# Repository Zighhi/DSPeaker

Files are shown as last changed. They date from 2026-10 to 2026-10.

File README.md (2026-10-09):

# DSPeaker

A DIY 2-way active desktop monitor: custom cabinets, an RP2040 running a hand-written fixed-point DSP crossover, and independent DACs giving each speaker its own full crossover network. Every DSP decision here was validated against real acoustic measurement, not tuned by ear.

<p align="center">
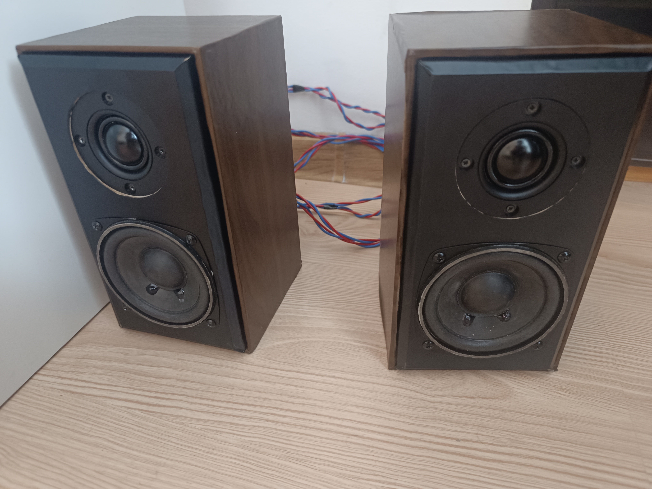
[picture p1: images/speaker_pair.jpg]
The finished stereo pair
  
</p>

## Measured Result

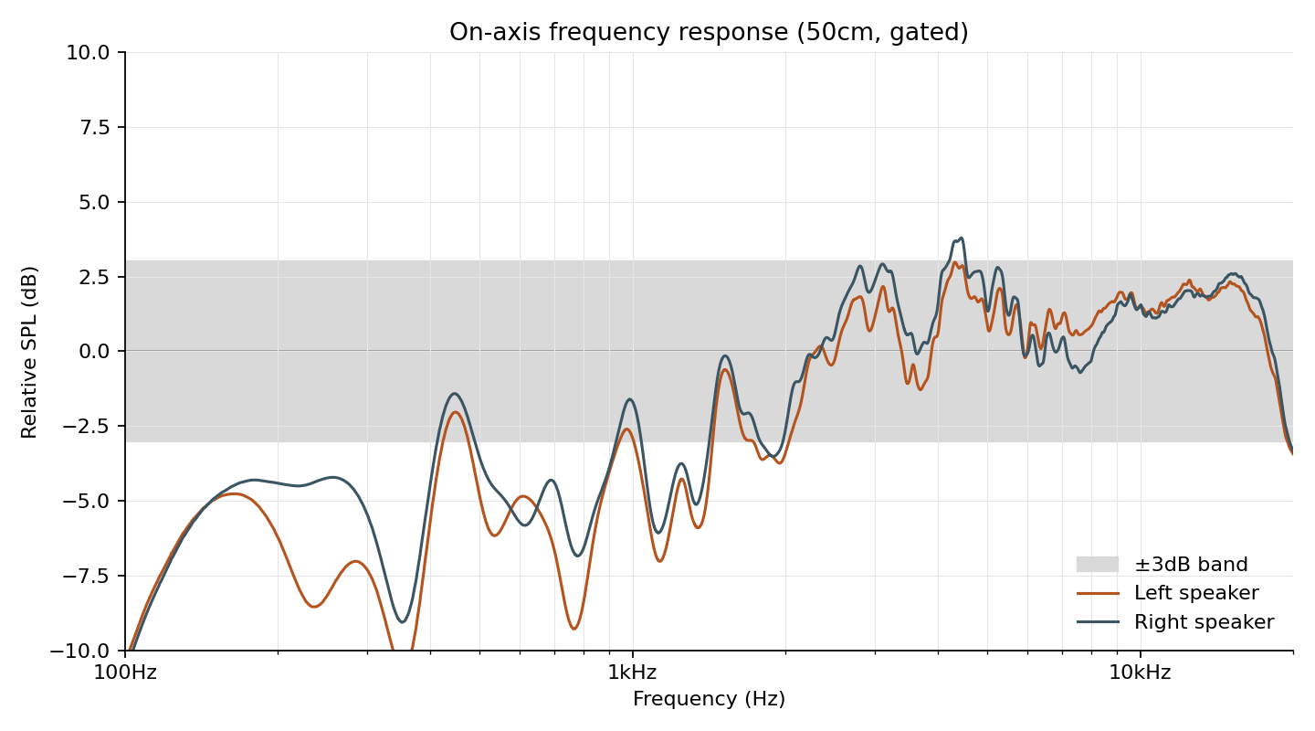
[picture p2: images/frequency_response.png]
On-axis frequency response


Gated 50cm on-axis, both speakers, raw/unsmoothed standard deviation **±2.65dB (Left) / ±2.47dB (Right)** across 100Hz–20kHz.

---

## Hardware

| | |
|---|---|
| **Tweeter** | Dayton Audio ND25FA-4 — 25mm silk dome, 4Ω, Re 3.2Ω, Fs 1350Hz, Qts 1.56, Sd 7.5cm², 90dB @ 2.83V/1m, 20W RMS, manufacturer usable range 2.5–20kHz (full manufacturer datasheet not redistributed here — search "Dayton Audio ND25FA-4" on their site for the original PDF) |
| **Woofer** | Unmarked ~75mm cone driver, Thiele-Small parameters measured directly — see [`driver_measurements`](driver_measurements): Re 5.50–5.57Ω, Fs 128.6–132.5Hz, Qts 1.702–1.858, Vas 0.92L, Sd 44.2cm², ≈81dB @ 1W/1m |
| **Amplification** | TPA3118D2 Class-D, 4 channels total (one per driver — tweeter and woofer never share a channel), run at 12V against a 24V/≈60W rating |
| **DSP** | Raspberry Pi RP2040 (Waveshare RP2040-Zero), no hardware FPU, 48kHz, fixed-point (Q28/Q31) |
| **Converters** | WM8782 ADC (stereo input), 2× PCM5102A DAC — one per speaker, each independently addressed, not a stereo pair sharing one chip |
| **Cabinet** | CNC-cut baffle/frame, front baffle 110×210mm, internal acoustic stuffing |

No standalone schematic exists for the electronics — the actual signal chain is fully specified in the pin-level comments at the top of [`miXZer.c`](firmware/miXZer/miXZer.c), and the real build is visible in the photos below. The perfboard carries the WM8782 ADC input stage, the RP2040-Zero, and the two PCM5102A DAC modules feeding the four TPA3118 amp channels.

<p align="center">
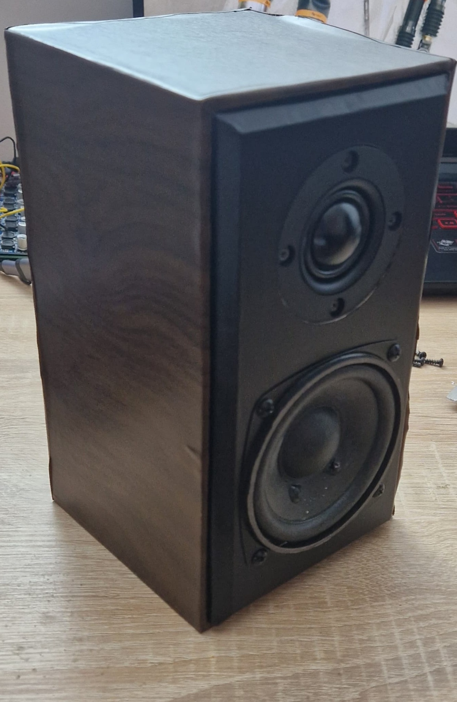
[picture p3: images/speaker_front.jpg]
Tweeter and woofer, front view
  
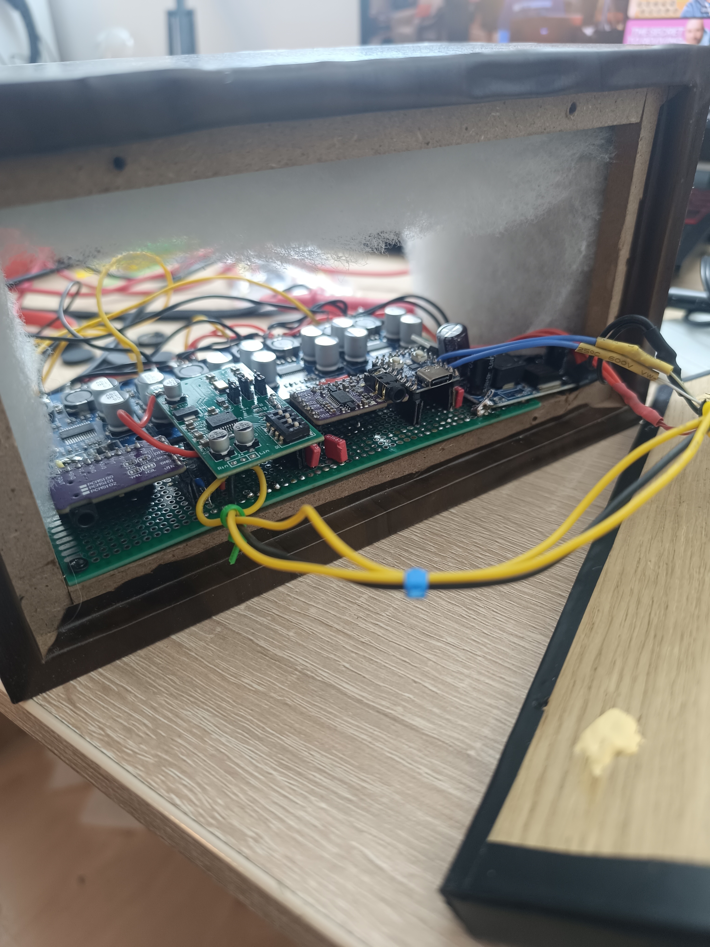
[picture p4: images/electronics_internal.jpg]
The electronics assembly inside the active cabinet
  
</p>

---

## Firmware & DSP

All of it lives in [`miXZer.c`](firmware/miXZer/miXZer.c) — one file, no RTOS, an interrupt-driven double-buffered DMA pipeline running the whole signal chain sample-by-sample in real time.

**Signal path:**
```
ADC (WM8782, stereo in)
      │
      ▼
 Baffle-step shelf (source L/R, pre-split)
      │
      ├──► Tweeter HPF (LR4, 3kHz) ──► amp1 (L) / amp3 (R)
      │
      └──► Woofer LPF (LR4, 3kHz) ──► level pad ──► amp2 (L) / amp4 (R)
```

Left and Right stay fully independent the entire way through — two DACs, two crossovers, never mixed.

**Fixed-point throughout.** The RP2040 has no hardware FPU — a float multiply costs ~80 cycles in software, not viable inside a 48kHz real-time budget. Filters run in Q0.31 where coefficients stay under 1.0, Q3.28 where they don't (the crossover biquads exceed ±1.0), multiplies widened to 64-bit before rescaling to avoid overflow.

**The crossover went through three real iterations:**
1. Two cascaded 1st-order HPF/LPF stages (LR2-equivalent) — a real destructive-interference notch showed up at 1.5–2.2kHz. A delay line made it worse in both directions. Root cause: LR2 only sums flat with one driver's polarity inverted.
2. With that fixed, the tweeter's own mechanical resonance (Fs=1350Hz, Qts 1.56) was only getting ~16dB of attenuation from the 2-pole HPF — audible as a +8–10dB peak at 1.4kHz. Bumping the tweeter HPF to 3 stages fixed the resonance but broke the matched-order flat-sum property, reopening a different ~9–10dB dip.
3. **Final: a real 4th-order Linkwitz-Riley (LR4)** — two cascaded 2nd-order Butterworth biquads per side, matched order, normal (non-inverted) polarity. Steeper than the 3-pole hack (−28.4dB at the tweeter's resonance, vs −24.1dB) *and* matched-order, so it sums flat on its own — verified flat to <1e-13dB across 500Hz–6kHz in the design math. The coefficient design tool is at [`design_tools/test_lr4_crossover.py`](firmware/miXZer/design_tools/test_lr4_crossover.py).

**Baffle-step compensation**: the 110mm baffle width gives a shelf corner at `115/0.11m ≈ 1045Hz`. A +4dB low shelf below that, applied pre-crossover-split, compensates for the cabinet losing half-space loading at low frequencies.

**Level matching**: no tweeter pad survived — estimated values gave wildly inconsistent results session to session, traced to measurement setup rather than the electronics. With no pad at all, a clean measurement showed the woofer running 4.36dB hot; the woofer gets that attenuation instead.

**Live diagnostics over USB serial**, no reflashing between measurement takes: `b`/`t`/`w` for both/tweeter-only/woofer-only, `s` to toggle the baffle-step shelf. A separate firmware, [`channel_id.c`](firmware/miXZer/channel_id.c), confirmed the amp-to-driver mapping by playing a distinct tone per channel: **amp1 = Left tweeter, amp2 = Left woofer, amp3 = Right tweeter, amp4 = Right woofer.**

---

## The Stereo-Imaging Bug

The single most important fix in the project, and it was silent — nothing sounded obviously broken. The original design treated the I2S Left/Right *slot* as meaning tweeter/woofer, and fed the second DAC as a literal mirror of the first. Source-Left reached *both* tweeters, source-Right reached *both* woofers — true stereo imaging was scrambled the whole time. Fixed by splitting each speaker's own source channel into its own tweeter/woofer feed, with the second DAC's buffer filled independently every sample instead of mirrored.

---

## Repository Structure

```
firmware/
├── miXZer/        Current firmware — miXZer.c (main DSP), channel_id.c
│                   (driver-identification tool), lib/ (PIO I2S driver),
│                   design_tools/ (LR4 coefficient calculator)
└── build_tools/    auto_flash_rp2040.py — the UF2 flashing script actually used

02_CAD_3D/
├── Cabinet_STEP_Models/   STEP models of the cabinets, baffles and frames
└── layout/                Perfboard layout (DIY Layout Creator) + PDF and netlist

driver_measurements/   Measured Thiele-Small parameters for both woofers

images/                 Build photos and the measured frequency response chart
```

---

## Building It Yourself

**Toolchain** (not vendored here — install yourself, pinned to what this was built/tested with):
- `arm-none-eabi-gcc` 14.2.1 (Release)
- CMake 3.29+
- Ninja
- [Raspberry Pi Pico SDK](https://github.com/raspberrypi/pico-sdk) 2.2.0

**Build:**
```
cd firmware/miXZer
python build_mixzer.py
```

**Flash** (board in BOOTSEL mode):
```
cd firmware/build_tools
python auto_flash_rp2040.py
```

By default this flashes `miXZer.uf2`; pass an explicit path as the first argument to flash something else (e.g. `channel_id.uf2`).

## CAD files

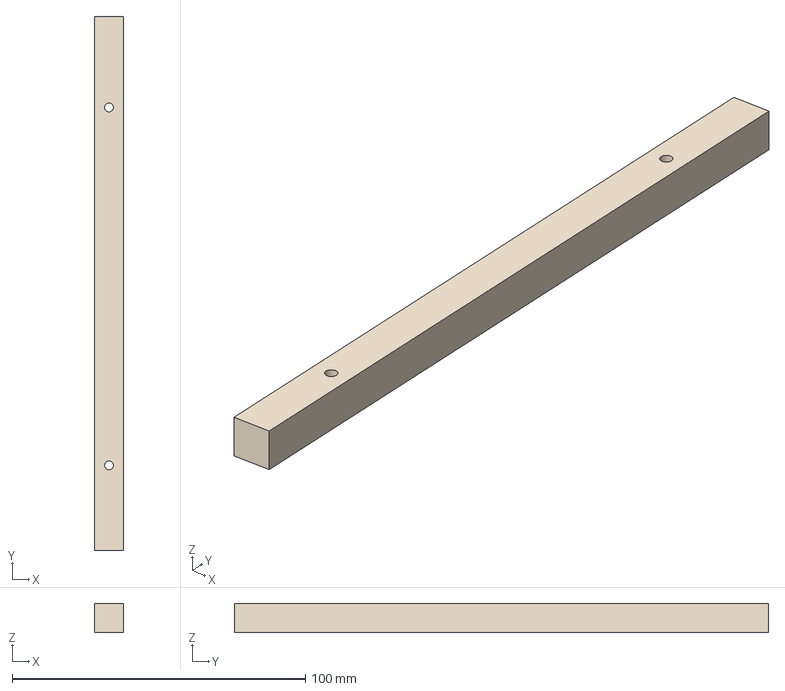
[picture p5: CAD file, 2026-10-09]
02_CAD_3D/Cabinet_STEP_Models/Cabinet_build/FrameA.step
10.0 x 182.0 x 10.0 mm

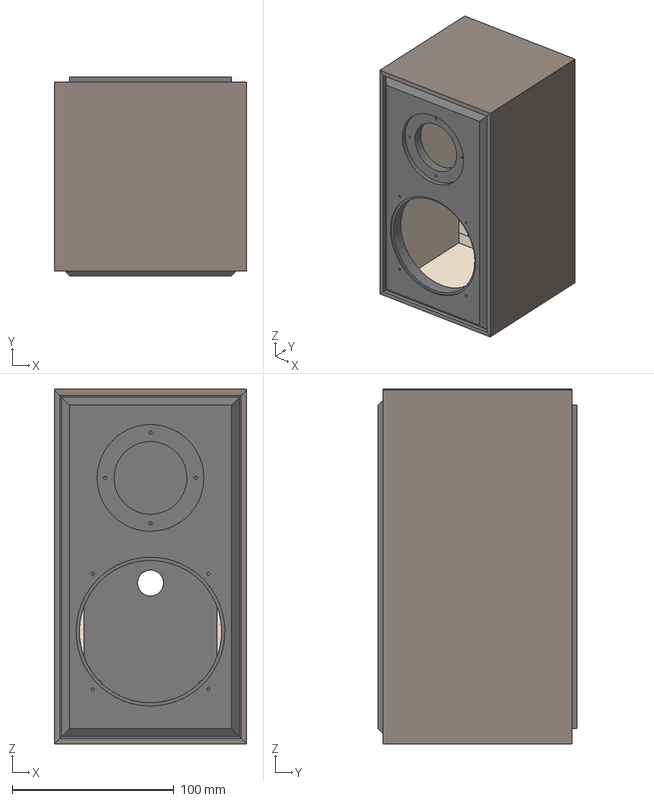
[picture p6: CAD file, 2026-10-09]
02_CAD_3D/Cabinet_STEP_Models/Cabinet_build/Active_Speaker.step
119.0 x 123.0 x 219.5 mm

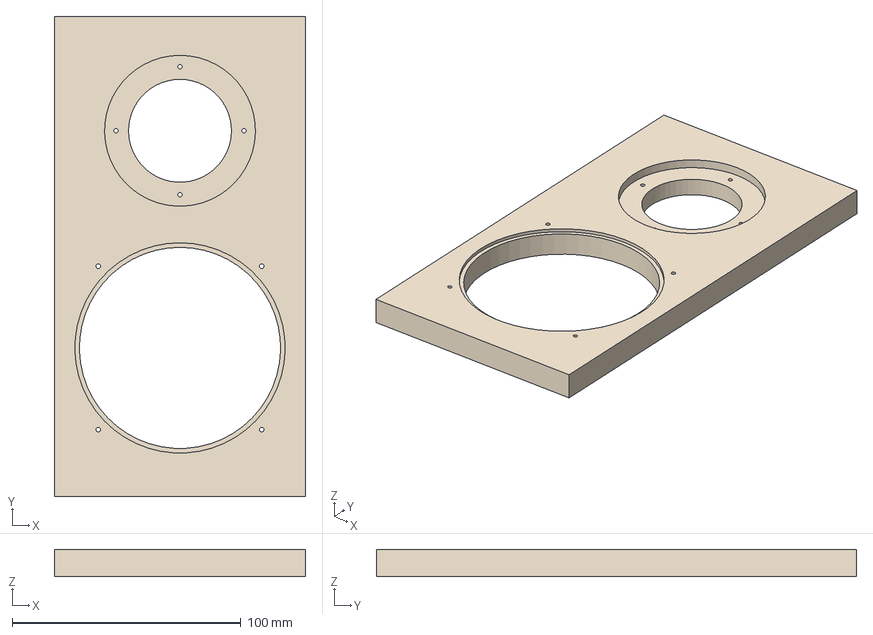
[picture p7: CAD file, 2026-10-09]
02_CAD_3D/Cabinet_STEP_Models/Cabinet_build/Speaker_Front_Baffle.step
110.0 x 210.0 x 12.0 mm

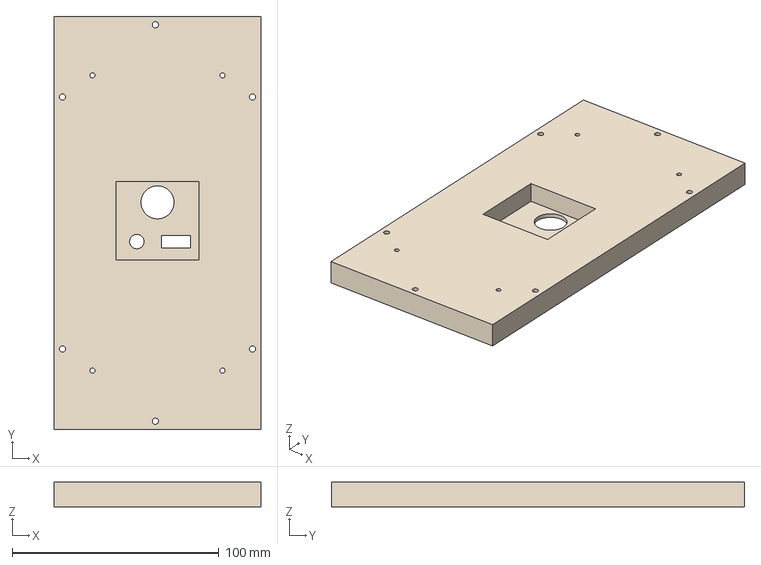
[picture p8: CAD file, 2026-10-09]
02_CAD_3D/Cabinet_STEP_Models/Cabinet_build/Active_Speaker_Back_Baffle.step
100.0 x 200.0 x 12.0 mm

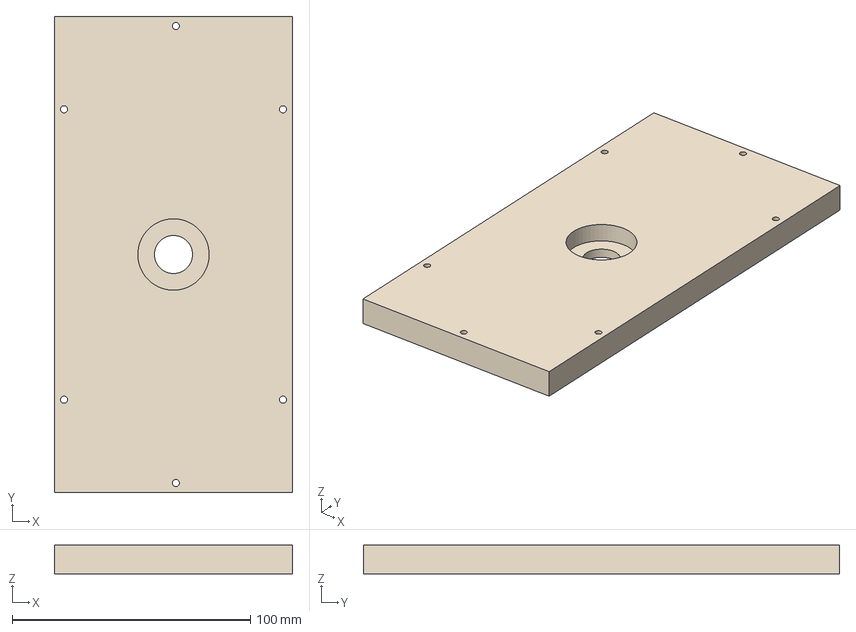
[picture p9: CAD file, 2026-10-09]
02_CAD_3D/Cabinet_STEP_Models/Cabinet_build/Passive_Speaker_Back_Baffle.step
100.0 x 200.0 x 12.0 mm

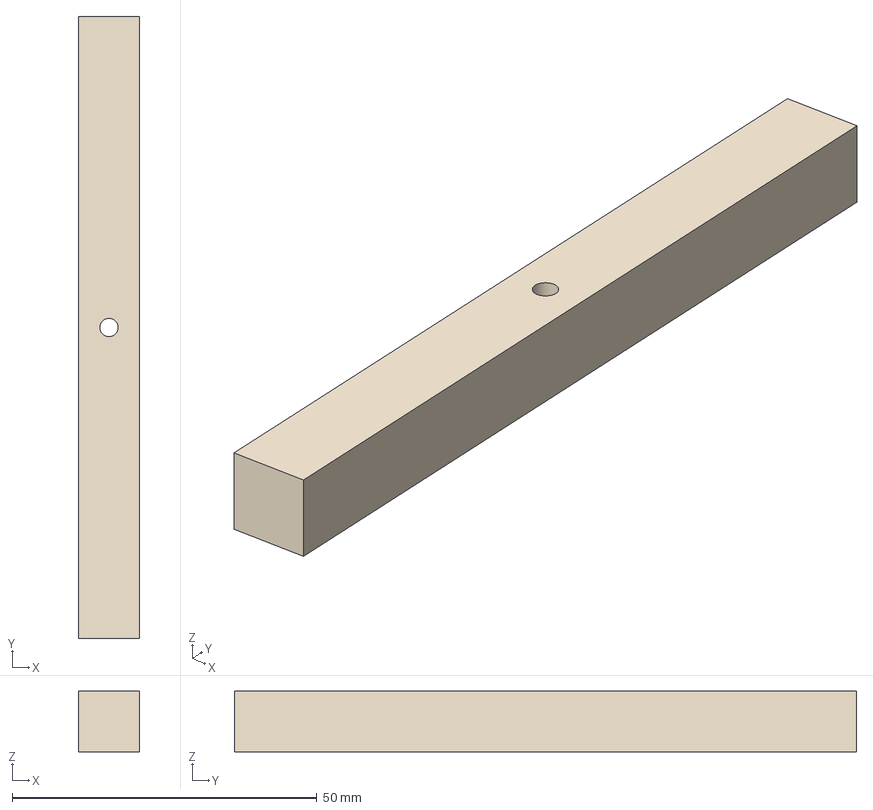
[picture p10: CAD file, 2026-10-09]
02_CAD_3D/Cabinet_STEP_Models/Cabinet_build/FrameB.step
10.0 x 102.0 x 10.0 mm

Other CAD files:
02_CAD_3D/Cabinet_STEP_Models/Cabinet_build/Passive_Speaker.step

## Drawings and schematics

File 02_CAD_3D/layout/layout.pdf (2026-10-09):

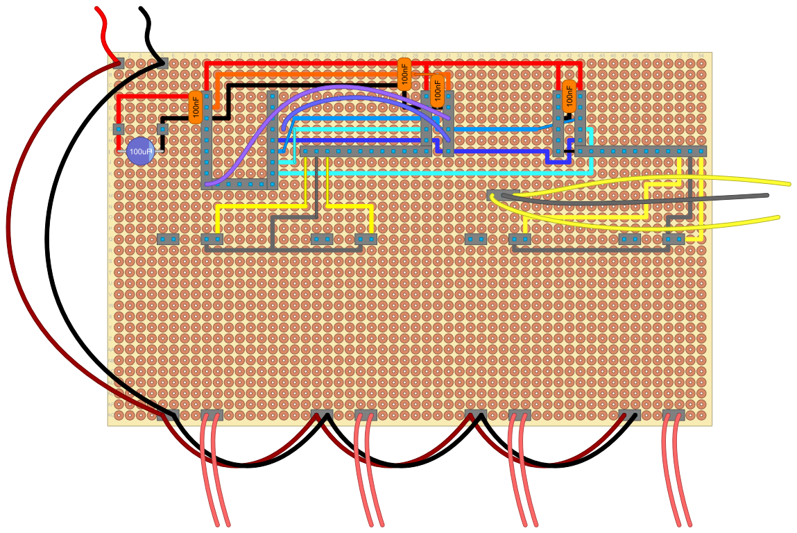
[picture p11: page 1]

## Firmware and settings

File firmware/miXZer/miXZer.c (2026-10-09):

#include <stdio.h>
#include <stdbool.h>
#include "pico/stdlib.h"
#include "hardware/clocks.h"
#include "i2s.h"
#include "hardware/dma.h"
#include "hardware/sync.h"

#define PIN_MCLK       14     // GP14: RP2040 -> SCK of WM8782 (12.288 MHz Master Clock)
                               // Isolated from the DIN/BCK/LRCK run to avoid crosstalk.
#define PIN_DIN_BASE   3      // GP3: WM8782 DOUT -> RP2040 (ADC Input Data)
#define PIN_BCK        4      // GP4: Shared Bit Clock (BCK) -- must be DIN+1, fixed by PIO design
#define PIN_LRCK       5      // GP5: Shared Frame Sync (LRCK) -- must be DIN+2, fixed by PIO design
#define PIN_DOUT       6      // GP6: RP2040 -> PCM5102A #1 DIN -> Left speaker (amp1 tweeter, amp2 woofer)
#define PIN_DOUT2      7      // GP7: RP2040 -> PCM5102A #2 DIN -> Right speaker (amp3 tweeter, amp4 woofer)
                               // Independently filled per-sample, NOT a mirror of DAC1
                               // -- see the per-speaker crossover block below.

// Bi-color power LED (salvaged laptop DC jack, two LED dies wired
// back-to-back across 2 leads -- color depends on current direction, not
// voltage level). Driven directly by two GPIOs acting as a push-pull pair;
// no H-bridge needed since a single low-current LED only needs two
// independent output drivers, which each GPIO already is on its own.
#define PIN_LED_A      15
#define PIN_LED_B      26

// Amp mute control: one BC337 transistor per Class-D board, base driven
// (through a resistor) from this single GPIO, collector/emitter across each
// board's mute-pin pair. GPIO HIGH saturates all 4 transistors, shorting
// all 4 mute-pin pairs at once (muted); LOW opens them (unmuted). Held high
// through boot to suppress the power-on pop while clocks/DSP settle.
#define PIN_MUTE       28

#define FS_HZ          48000  // 48 kHz
#define SCK_MULT       256    // 256 * fs = 12.288 MHz
#define BIT_DEPTH      32     // 24-bit audio in 32-bit I2S slots (64 * fs BCK = 3.072 MHz)

// Let clocks and the WM8782 fully settle/sync before releasing mute.
#define BOOT_SETTLE_DELAY_MS 2000

static __attribute__((aligned(8))) pio_i2s i2sA;
static volatile uint32_t half_idx = 0;
static uint dac2_dma_channel;
static volatile bool dac2_ready = false; // guards against the ISR firing before DAC2 init completes

// --- Per-speaker active crossover ---
// Confirmed via the channel_id.c identification tool:
//   amp1 (DAC1-Left)  = Left speaker tweeter
//   amp2 (DAC1-Right) = Left speaker woofer
//   amp3 (DAC2-Left)  = Right speaker tweeter
//   amp4 (DAC2-Right) = Right speaker woofer
// DAC2 is filled independently here, NOT mirrored from DAC1 --
// i2s_mirrored_output_feed() just DMAs whatever buffer it's handed, it
// doesn't require that buffer to be DAC1's own (proven in channel_id.c).
// So each speaker gets its OWN source channel split into a tweeter feed
// and a woofer feed, instead of the old scheme where the I2S Left/Right
// *slot* itself meant tweeter/woofer -- that sent the source's Left
// channel to both tweeters and Right channel to both woofers,
// scrambling stereo imaging. Now:
//   DAC1-Left  (amp1) = HPF(source Left)
//   DAC1-Right (amp2) = LPF(source Left)
//   DAC2-Left  (amp3) = HPF(source Right)
//   DAC2-Right (amp4) = LPF(source Right)
//
// Crossover is a real 4th-order Linkwitz-Riley (LR4) at fc=3kHz: two
// cascaded 2nd-order Butterworth (Q=0.7071) biquads per side, matched
// order on both HPF and LPF. This replaced an earlier design that
// cascaded three 1-pole HPF stages against a 2-pole LPF -- that gave
// enough extra slope to tame the tweeter's own Fs=1350Hz resonance, but
// the order mismatch broke the clean polarity-flip flat-sum property
// and left a real ~9-10dB dip around 1.8kHz in measurement. LR4 fixes
// both at once: it's steeper than that 3-pole hack (-28.4dB at 1350Hz
// vs -24.1dB before, so tweeter protection is if anything better) AND
// matched order, so it sums flat on its own. Verified in the filter
// design math before flashing: same-polarity sum is flat to numerical
// noise (<1e-13dB) across 500Hz-6kHz, while inverted-polarity summing
// (what the old LR2-style design needed) produces a near-total null
// right at crossover instead -- so unlike before, the woofer path here
// runs at NORMAL polarity, no inversion.
//
// RP2040 has no hardware FPU (float is ~80 cycles/op), so this runs in
// fixed point: Direct Form I biquad,
//   y[n] = b0*x[n] + b1*x[n-1] + b2*x[n-2] - a1*y[n-1] - a2*y[n-2]
// Coefficients are Q3.28, not Q0.31 -- some of them exceed +-1.0 (e.g.
// the HPF's b1 = -1.514), so Q0.31's [-1, 1) range doesn't have the
// headroom. Multiplies run in 64-bit to avoid overflow, then rescale
// back down by the Q28 shift.
#define BIQUAD_SHIFT 28
typedef struct { int32_t x1, x2, y1, y2; } biquad_state_t;

// LR4 @ fc=3kHz, fs=48kHz, Q=0.7071 (Butterworth) per stage.
// (b0, b1, b2, a1, a2) in Q28.
static const int32_t HPF_BIQUAD_Q28[5] = { 203226142, -406452284, 203226142, -390370540, 154098572 };
static const int32_t LPF_BIQUAD_Q28[5] = {   8040872,   16081744,   8040872, -390370540, 154098572 };

// Level matching: a tweeter pad (estimated ~7dB, then a
// measurement-corrected ~13.4dB) gave inconsistent gap results across
// sessions (+6.41dB, then -2.53dB, then -16.5dB with the same firmware
// and no code changes in between), so it was pulled entirely. With no
// pad at all, a clean gated measurement (Sep 15) showed the woofer
// running 4.36dB hotter than the tweeter -- the woofer path gets that
// attenuation instead. Pure attenuation (gain < 1, Q0.31) rather than
// boosting the tweeter, to avoid needing extra fixed-point headroom
// and any risk of clipping.
#define WOOFER_PAD_Q31    1299959630   // 0.605341 (~-4.36dB, measured Sep 15)

// Baffle step compensation: below a frequency set by the front baffle's
// width, a driver radiates into full space instead of half space and
// loses up to ~6dB on-axis. Baffle is 110mm wide (from the CAD model,
// both drivers centered on that dimension), giving f_bs = 115/0.11m =
// ~1045Hz. Applied as a +4dB low shelf (conservative vs the full 6dB,
// since these sit close to room boundaries at the listening position
// and will pick up some of that gain from the room itself) to the
// source signal before it splits into the tweeter/woofer crossover, so
// whichever driver covers that range gets the correction.
#define BSC_LPF_ALPHA_Q31 258505988    // 0.120376, fc=1045.5Hz
#define BSC_BOOST_Q31     1256048567   // 0.584893 (G-1) for +4dB shelf

// History, for whoever reads this next: the original crossover was two
// cascaded 1st-order complementary HPF/LPF stages each (LR2-equivalent),
// which needed the woofer polarity inverted to sum flat -- confirmed by
// a real destructive-interference notch at 1.5-2.2kHz that a 30-sample
// delay (tried both directions) only made worse, but polarity inversion
// fixed outright. That got the tweeter's own Fs=1350Hz resonance poking
// through as a +8-10dB peak, so the tweeter HPF was bumped to 3 cascaded
// stages (18dB/oct) while the woofer LPF stayed 2-pole (12dB/oct) --
// fixed the resonance, but the resulting order mismatch broke the clean
// polarity-flip flat-sum property and left a real ~9-10dB dip around
// 1.8kHz. The LR4 design above replaced all of that at once: matched
// order on both sides, steeper than the 3-pole hack, normal (not
// inverted) woofer polarity. No added delay in any of this -- tested
// directly, it never helped; these two drivers are close enough
// together on the baffle that a timing correction isn't needed.
typedef struct { int32_t prev_x, prev_y; } filter_state_t;  // used by the BSC shelf below, not the crossover

static biquad_state_t hpfL1, hpfL2;  // source Left  -> amp1 (Left tweeter), LR4 = 2 cascaded Butterworth stages
static biquad_state_t hpfR1, hpfR2;  // source Right -> amp3 (Right tweeter)
static biquad_state_t lpfL1, lpfL2;  // source Left  -> amp2 (Left woofer)
static biquad_state_t lpfR1, lpfR2;  // source Right -> amp4 (Right woofer)

static filter_state_t bscL, bscR;  // baffle-step shelf, applied pre-crossover-split

static int32_t dac2_buf[STEREO_BUFFER_SIZE];

// --- Live driver isolation mode, switched over USB serial ---
// For measuring each driver's real, in-crossover response in isolation
// (e.g. tweeter level vs woofer level) without physically disconnecting
// speaker wire between takes. Send a single character over the USB
// serial connection at any time:
//   b/B = both (normal operation)
//   t/T = tweeters only (woofers muted, both speakers)
//   w/W = woofers only (tweeters muted, both speakers)
//   s/S = toggle baffle-step shelf on/off, for a clean back-to-back A/B
//         at a fixed mic position instead of comparing across sessions
typedef enum { MODE_BOTH = 0, MODE_TWEETERS_ONLY, MODE_WOOFERS_ONLY } output_mode_t;
static volatile output_mode_t output_mode = MODE_BOTH;
static volatile bool bsc_enabled = true;

// Direct Form I biquad, coefficients c[] = {b0,b1,b2,a1,a2} in Q28.
static inline int32_t biquad_process(int32_t x, biquad_state_t *s, const int32_t *c)
{
    int64_t acc = (int64_t)c[0] * x + (int64_t)c[1] * s->x1 + (int64_t)c[2] * s->x2
                - (int64_t)c[3] * s->y1 - (int64_t)c[4] * s->y2;
    int32_t y = (int32_t)(acc >> BIQUAD_SHIFT);
    s->x2 = s->x1; s->x1 = x;
    s->y2 = s->y1; s->y1 = y;
    return y;
}

static inline int32_t apply_woofer_pad(int32_t x)
{
    return (int32_t)(((int64_t)WOOFER_PAD_Q31 * (int64_t)x) >> 31);
}

// Low shelf: y = x + (G-1)*LPF(x). Unlike every other stage here this one
// adds gain, so unlike the others it can push a sample past full scale on
// already-hot bass content -- clamp instead of letting it wrap around.
static inline int32_t apply_bsc(int32_t x, filter_state_t *s)
{
    int64_t diff = (int64_t)x - (int64_t)s->prev_y;
    int32_t lp = s->prev_y + (int32_t)(((int64_t)BSC_LPF_ALPHA_Q31 * diff) >> 31);
    s->prev_x = x;
    s->prev_y = lp;
    int64_t boosted = ((int64_t)BSC_BOOST_Q31 * (int64_t)lp) >> 31;
    int64_t y = (int64_t)x + boosted;
    if (y > INT32_MAX) y = INT32_MAX;
    else if (y < INT32_MIN) y = INT32_MIN;
    return (int32_t)y;
}

// ISR timing-jitter detector. Each half-buffer is 48 frames @ 48kHz, so this
// IRQ should fire every ~1000us like clockwork. A real-time miss here (DMA
// not keeping the PIO TX FIFO fed, or the ISR itself running late) is
// exactly what an audible crackle/click sounds like -- catch it directly
// instead of guessing at the cause.
#define EXPECTED_IRQ_INTERVAL_US 1000
#define GLITCH_THRESHOLD_US      200   // +/- 20% off expected counts as a glitch
static volatile uint32_t last_irq_time_us = 0;
static volatile uint32_t glitch_count      = 0;
static volatile uint32_t max_interval_us   = 0;
static volatile uint32_t worst_glitch_us   = 0;

// IRQ handler: per-speaker crossover + driver isolation
static void __isr dma_irq_handler(void)
{
    uint32_t now = time_us_32();
    if (last_irq_time_us != 0) {
        uint32_t interval = now - last_irq_time_us;
        if (interval > max_interval_us) max_interval_us = interval;
        uint32_t deviation = (interval > EXPECTED_IRQ_INTERVAL_US)
                                 ? (interval - EXPECTED_IRQ_INTERVAL_US)
                                 : (EXPECTED_IRQ_INTERVAL_US - interval);
        if (deviation > GLITCH_THRESHOLD_US) {
            ++glitch_count;
            if (interval > worst_glitch_us) worst_glitch_us = interval;
        }
    }
    last_irq_time_us = now;

    dma_hw->ints0 = 1u << i2sA.dma_ch_in_data;

    int32_t *in_half  = i2sA.in_ctrl_blocks[half_idx];
    int32_t *out_half = i2sA.out_ctrl_blocks[half_idx];

    for (size_t i = 0; i < STEREO_BUFFER_SIZE; i += 2)
    {
        int32_t src_left  = bsc_enabled ? apply_bsc(in_half[i], &bscL)
                                        : in_half[i];
        int32_t src_right = bsc_enabled ? apply_bsc(in_half[i + 1], &bscR)
                                         : in_half[i + 1];

        // Left speaker (amp1 tweeter / amp2 woofer), both from source Left --
        // LR4: two cascaded Butterworth biquads per side, normal polarity
        int32_t tw_l = biquad_process(src_left, &hpfL1, HPF_BIQUAD_Q28);
        tw_l = biquad_process(tw_l, &hpfL2, HPF_BIQUAD_Q28);
        int32_t wf_l = biquad_process(src_left, &lpfL1, LPF_BIQUAD_Q28);
        wf_l = apply_woofer_pad(biquad_process(wf_l, &lpfL2, LPF_BIQUAD_Q28));

        // Right speaker (amp3 tweeter / amp4 woofer), both from source Right
        int32_t tw_r = biquad_process(src_right, &hpfR1, HPF_BIQUAD_Q28);
        tw_r = biquad_process(tw_r, &hpfR2, HPF_BIQUAD_Q28);
        int32_t wf_r = biquad_process(src_right, &lpfR1, LPF_BIQUAD_Q28);
        wf_r = apply_woofer_pad(biquad_process(wf_r, &lpfR2, LPF_BIQUAD_Q28));

        // Live driver isolation for measurement (see output_mode above) --
        // filters above still run either way, so state stays continuous
        // and there's no click/discontinuity switching modes mid-stream.
        if (output_mode == MODE_TWEETERS_ONLY) {
            wf_l = 0;
            wf_r = 0;
        } else if (output_mode == MODE_WOOFERS_ONLY) {
            tw_l = 0;
            tw_r = 0;
        }

        out_half[i]     = tw_l;   // DAC1-Left  -> amp1
        out_half[i + 1] = wf_l;   // DAC1-Right -> amp2
        dac2_buf[i]     = tw_r;   // DAC2-Left  -> amp3
        dac2_buf[i + 1] = wf_r;   // DAC2-Right -> amp4
    }

    // DAC #2 is independently filled above (see per-speaker crossover
    // block) -- this feeds that buffer out, not a mirror of DAC1's.
    if (dac2_ready) {
        i2s_mirrored_output_feed(dac2_dma_channel, dac2_buf);
    }

    half_idx ^= 1u;
}

int main(void)
{
    stdio_init_all();
    sleep_ms(1000);

    gpio_init(PIN_LED_A);
    gpio_init(PIN_LED_B);
    gpio_set_dir(PIN_LED_A, GPIO_OUT);
    gpio_set_dir(PIN_LED_B, GPIO_OUT);
    gpio_put(PIN_LED_A, false);  // start on "amber": muted/starting up (A low, B high --
    gpio_put(PIN_LED_B, true);   // swapped from the first guess to match the real LED wiring)

    gpio_init(PIN_MUTE);
    gpio_set_dir(PIN_MUTE, GPIO_OUT);
    gpio_put(PIN_MUTE, true);    // muted at boot -- released once the audio path is confirmed stable

    set_sys_clock_khz(132000, true);

    i2s_config cfg = {
        .fs             = FS_HZ,
        .sck_mult       = SCK_MULT,
        .bit_depth      = BIT_DEPTH,
        .sck_pin        = PIN_MCLK,
        .dout_pin       = PIN_DOUT,
        .din_pin        = PIN_DIN_BASE,
        .clock_pin_base = PIN_BCK,
        .sck_enable     = true,
    };

    i2s_program_start_synched(pio0, &cfg, dma_irq_handler, &i2sA);

    // EMI mitigation: MCLK is isolated on GP14 so it can stay fast/full
    // drive for signal integrity. BCK/LRCK sit permanently adjacent to DIN
    // (fixed by the PIO's pin layout), so slow their edges down to reduce
    // crosstalk into the ADC data line.
    //
    // (Tested fast/full-drive BCK/LRCK as a DAC2-distortion diagnostic --
    // made no difference, so it's not a signal-integrity issue. Reverted.)
    gpio_set_drive_strength(PIN_MCLK, GPIO_DRIVE_STRENGTH_4MA);
    gpio_set_slew_rate(PIN_MCLK, GPIO_SLEW_RATE_FAST);
    gpio_set_drive_strength(PIN_BCK,  GPIO_DRIVE_STRENGTH_2MA);
    gpio_set_slew_rate(PIN_BCK,  GPIO_SLEW_RATE_SLOW);
    gpio_set_drive_strength(PIN_LRCK, GPIO_DRIVE_STRENGTH_2MA);
    gpio_set_slew_rate(PIN_LRCK, GPIO_SLEW_RATE_SLOW);

    // Second output for PCM5102 #2, slaved to the BCK/LRCK the sync above
    // already generates. Independently filled per-sample by the
    // per-speaker crossover in the ISR (see dac2_buf) -- not a mirror.
    // Runs on PIO1, not PIO0: PIO0 is already full (SCK + in-slave +
    // out-master = 3 programs sharing its 32-instruction memory), and a 4th
    // program there overflows it and corrupts the other three. PIO1 is
    // completely free and can still read GP3/4/5 (DIN/BCK/LRCK) fine --
    // GPIO inputs are readable by either PIO block regardless of which one
    // drives them.
    dac2_dma_channel = i2s_add_mirrored_output(pio1, &i2sA, PIN_DOUT2, PIN_DIN_BASE);
    dac2_ready = true;

    printf("\nAudio passthrough running (both DACs). Settling %d ms before unmute...\n",
           BOOT_SETTLE_DELAY_MS);
    sleep_ms(BOOT_SETTLE_DELAY_MS);

    // Audio path confirmed stable at this point (clocks settled, both DACs
    // running) -- release mute and flip the LED to "white" (running).
    gpio_put(PIN_MUTE, false);
    gpio_put(PIN_LED_A, true);
    gpio_put(PIN_LED_B, false);

    // The periodic "ISR timing" status report and the bulk audio-capture
    // dump that used to live here have both done their jobs (glitches
    // reliably read 0, and the capture caught the ground-loop click back
    // when that was the mystery). Removed -- that recurring USB CDC
    // traffic was itself a source of audible artifacts once the amps were
    // unmuted, and neither is needed now. The underlying glitch_count/
    // worst_glitch_us/max_interval_us tracking in the ISR is left in place
    // and still accumulates silently -- add a printf back here if it's
    // ever needed for debugging again.

    printf("\nDriver isolation mode: send 'b'=both 't'=tweeters-only 'w'=woofers-only over serial\n");
    printf("Current mode: BOTH\n\n");

    while (true)
    {
        sleep_ms(200);

        int c = getchar_timeout_us(0);
        if (c != PICO_ERROR_TIMEOUT) {
            if (c == 'b' || c == 'B') {
                output_mode = MODE_BOTH;
                printf("Mode: BOTH (tweeters + woofers, normal operation)\n");
            } else if (c == 't' || c == 'T') {
                output_mode = MODE_TWEETERS_ONLY;
                printf("Mode: TWEETERS ONLY (woofers muted, both speakers)\n");
            } else if (c == 'w' || c == 'W') {
                output_mode = MODE_WOOFERS_ONLY;
                printf("Mode: WOOFERS ONLY (tweeters muted, both speakers)\n");
            } else if (c == 's' || c == 'S') {
                bsc_enabled = !bsc_enabled;
                printf("Baffle-step shelf: %s\n", bsc_enabled ? "ON (+4dB below ~1045Hz)" : "OFF (bypassed)");
            }
        }
    }
}

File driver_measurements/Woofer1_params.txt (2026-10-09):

TS Parameters file
Room EQ V5.31.3
Dated: Jul 26, 2026 6:56:41 PM
From measurement L Woofer 1 - Free Air Jul 26

Zmin 5.72 ohm
fmin 368 Hz
f3 3546 Hz
Le(f3) 0.176 mH
Motional impedance parameters
R0 22.84 ohm
CMES 566.1 uF
L0 2.619 mH
beta 0.0523 
omega0 1212.8 
Blocked impedance parameters
RDC 5.60 ohm
dR -0.03 ohm
Re 5.57 ohm
Leb 0.0 uH
Le 0.327 mH
Rss 298.0 ohm
Ke 0.0602 S-H
Thiele-Small parameters
fs 128.6 Hz
Qms 6.866
Qes 2.548
Qts 1.858
Fts 69.2
Mms 4.61 g
Cms 0.333 mm/N
Rms 0.542 kg/s
Vas 0.92 litres
Bl 2.852 Tm
Eta 0.08 %
Lp (1W/1m) 80.91 dB
Dd 7.50 cm
Sd 44.2 cm^2
Added mass measurement: L Woofer 1 - Added Mass Jul 26
Added mass 4.000 g
Air temperature 20.0 C
Air pressure 1013.25 mB
Air density 1.2041 kg/m^3
Speed of sound 343.2 m/s

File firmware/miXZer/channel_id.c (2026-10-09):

#include <stdio.h>
#include <stdbool.h>
#include "pico/stdlib.h"
#include "hardware/clocks.h"
#include "i2s.h"
#include "hardware/dma.h"
#include "hardware/sync.h"

// Same physical pins as miXZer.c -- the DACs/amps are wired the same
// regardless of which firmware is running.
#define PIN_MCLK       14
#define PIN_DIN_BASE   3
#define PIN_BCK        4
#define PIN_LRCK       5
#define PIN_DOUT       6
#define PIN_DOUT2      7
#define PIN_MUTE       28

#define FS_HZ          48000
#define SCK_MULT       256
#define BIT_DEPTH      32

static __attribute__((aligned(8))) pio_i2s i2sA;
static volatile uint32_t half_idx = 0;
static uint dac2_dma_channel;
static volatile bool dac2_ready = false;

// ============================================================
// Channel identification tone generator -- true 4-way isolation
// ============================================================
// i2s_mirrored_output_feed() just DMAs whatever buffer pointer it's
// given out to DAC2 -- it only "mirrors" DAC1 because miXZer.c happens
// to pass it DAC1's own out_half buffer. Here DAC2 gets its own,
// independently-filled buffer (dac2_buf), so all four channels can be
// exercised one at a time with nothing else making sound at all:
//   0: DAC1-Left  -> amp1
//   1: DAC1-Right -> amp2
//   2: DAC2-Left  -> amp3
//   3: DAC2-Right -> amp4
// Every other channel is silent while one plays, so whichever driver
// makes sound is unambiguously the one just announced over serial.
//
// A distinct note per channel, all in a moderate, safe mid-range (C5,
// G5, C6, G6 -- ~522/774/1043/1600 Hz) so each channel is identifiable
// by ear alone as well as by the serial log. Deliberately not spanning
// into deep bass or extreme treble for any one channel, since assuming
// which channel is a tweeter vs a woofer is exactly what this tool
// exists to NOT assume. Fixed-point square wave (RP2040 has no
// hardware FPU), no trig needed -- half-period in samples per channel.
#define TONE_AMPLITUDE     2000000    // ~24% of full-scale (+-8.4M for 24-bit)
#define PLAY_SAMPLES       (FS_HZ * 3 / 2)   // 1.5s tone
#define SILENCE_SAMPLES    (FS_HZ / 2)       // 0.5s gap between channels

static const int channel_half_period[4] = { 46, 31, 23, 15 }; // ~C5,G5,C6,G6

static const char *channel_label[4] = {
    "amp1  (DAC1-Left)   -- C5, ~522Hz",
    "amp2  (DAC1-Right)  -- G5, ~774Hz",
    "amp3  (DAC2-Left)   -- C6, ~1043Hz",
    "amp4  (DAC2-Right)  -- G6, ~1600Hz",
};

static volatile int      cycle_state      = 0;   // 0..3, which channel is active
static volatile bool     in_gap           = false;
static volatile uint32_t samples_in_state = 0;
static volatile uint32_t phase_count      = 0;
static volatile int32_t  square           = TONE_AMPLITUDE;
static volatile bool     announce_pending = true;

static int32_t dac2_buf[STEREO_BUFFER_SIZE];

static void __isr dma_irq_handler(void)
{
    dma_hw->ints0 = 1u << i2sA.dma_ch_in_data;

    int32_t *out_half = i2sA.out_ctrl_blocks[half_idx];

    int target_dac  = cycle_state >> 1;   // 0 = DAC1, 1 = DAC2
    int target_slot = cycle_state & 1;    // 0 = Left sample, 1 = Right sample

    for (size_t i = 0; i < STEREO_BUFFER_SIZE; ++i)
    {
        int slot = (int)(i & 1u);
        bool tone_here = !in_gap && (slot == target_slot);
        int32_t tone_val = tone_here ? square : 0;

        out_half[i] = (target_dac == 0) ? tone_val : 0;
        dac2_buf[i] = (target_dac == 1) ? tone_val : 0;

        if (tone_here) {
            if (++phase_count >= (uint32_t)channel_half_period[cycle_state]) {
                phase_count = 0;
                square = -square;
            }
        }

        // Advance the play/gap/next-channel state machine once per frame
        // (every Right-slot sample), not once per raw sample.
        if (slot == 1) {
            uint32_t limit = in_gap ? SILENCE_SAMPLES : PLAY_SAMPLES;
            if (++samples_in_state >= limit) {
                samples_in_state = 0;
                phase_count = 0;
                square = TONE_AMPLITUDE;
                if (in_gap) {
                    in_gap = false;
                    cycle_state = (cycle_state + 1) & 3;
                    announce_pending = true;
                } else {
                    in_gap = true;
                }
            }
        }
    }

    if (dac2_ready) {
        i2s_mirrored_output_feed(dac2_dma_channel, dac2_buf);
    }

    half_idx ^= 1u;
}

int main(void)
{
    stdio_init_all();
    sleep_ms(1000);

    gpio_init(PIN_MUTE);
    gpio_set_dir(PIN_MUTE, GPIO_OUT);
    gpio_put(PIN_MUTE, true);   // muted while clocks settle

    set_sys_clock_khz(132000, true);

    i2s_config cfg = {
        .fs             = FS_HZ,
        .sck_mult       = SCK_MULT,
        .bit_depth      = BIT_DEPTH,
        .sck_pin        = PIN_MCLK,
        .dout_pin       = PIN_DOUT,
        .din_pin        = PIN_DIN_BASE,
        .clock_pin_base = PIN_BCK,
        .sck_enable     = true,
    };

    i2s_program_start_synched(pio0, &cfg, dma_irq_handler, &i2sA);

    gpio_set_drive_strength(PIN_MCLK, GPIO_DRIVE_STRENGTH_4MA);
    gpio_set_slew_rate(PIN_MCLK, GPIO_SLEW_RATE_FAST);
    gpio_set_drive_strength(PIN_BCK,  GPIO_DRIVE_STRENGTH_2MA);
    gpio_set_slew_rate(PIN_BCK,  GPIO_SLEW_RATE_SLOW);
    gpio_set_drive_strength(PIN_LRCK, GPIO_DRIVE_STRENGTH_2MA);
    gpio_set_slew_rate(PIN_LRCK, GPIO_SLEW_RATE_SLOW);

    dac2_dma_channel = i2s_add_mirrored_output(pio1, &i2sA, PIN_DOUT2, PIN_DIN_BASE);
    dac2_ready = true;

    printf("\nChannel ID tool running -- true 4-way isolation.\n");
    printf("Each channel plays alone for 1.5s (~1500Hz), then 0.5s silence,\n");
    printf("then the next one. Everything else stays silent throughout.\n\n");
    printf("Settling before unmuting...\n");
    sleep_ms(1500);
    gpio_put(PIN_MUTE, false);
    printf("Unmuted -- cycling now.\n\n");

    while (true) {
        sleep_ms(20);
        if (announce_pending) {
            announce_pending = false;
            printf(">>> Now playing: %s\n", channel_label[cycle_state]);
        }
    }
}

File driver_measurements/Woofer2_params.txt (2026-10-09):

TS Parameters file
Room EQ V5.31.3
Dated: Jul 26, 2026 7:16:18 PM
From measurement L Woofer 2 - Free Air Jul 26

Zmin 5.73 ohm
fmin 383 Hz
f3 3191 Hz
Le(f3) 0.195 mH
Motional impedance parameters
R0 25.59 ohm
CMES 495.4 uF
L0 2.816 mH
beta 0.0542 
omega0 1249.5 
Blocked impedance parameters
RDC 5.60 ohm
dR -0.10 ohm
Re 5.50 ohm
Leb 0.0 uH
Le 0.395 mH
Rss 1562.3 ohm
Ke 0.0595 S-H
Thiele-Small parameters
fs 132.5 Hz
Qms 6.830
Qes 2.268
Qts 1.702
Fts 77.8
Mms 4.35 g
Cms 0.332 mm/N
Rms 0.530 kg/s
Vas 0.92 litres
Bl 2.962 Tm
Eta 0.09 %
Lp (1W/1m) 81.80 dB
Dd 7.50 cm
Sd 44.2 cm^2
Added mass measurement: L Woofer 2 - Added Mass Jul 26
Added mass 4.000 g
Air temperature 20.0 C
Air pressure 1013.25 mB
Air density 1.2041 kg/m^3
Speed of sound 343.2 m/s

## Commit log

2026-10-09 DSPeaker: active 2-way monitor, RP2040 fixed-point DSP crossover
    Custom-built active speaker pair: WM8782 ADC in, a hand-written
    fixed-point LR4 crossover plus baffle-step and level-matching
    correction on an RP2040, two independent PCM5102A DACs driving four
    TPA3118D2 amp channels (one per driver, never shared).
    Repo holds the firmware, measured driver Thiele-Small parameters,
    build photos, and the final gated frequency-response measurement.
    [Active_Speaker.step, Active_Speaker_Back_Baffle.step, FrameA.step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]
2026-10-09 Fix LR4 design tool (3 kHz, Hz units, prints firmware Q28 values); portable build/flash paths; document CAD folder
